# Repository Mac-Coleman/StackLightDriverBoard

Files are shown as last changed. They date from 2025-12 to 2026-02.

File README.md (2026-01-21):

# Stack Light Driver Board

This repository hosts my KiCad project.

Currently there is only a schematic.

Footprints and 3D models of most components are provided by [CDFER's JLCPCB component library for KiCad](https://github.com/CDFER/JLCPCB-Kicad-Library).

## Footprints and 3D models of the following components provided by SnapMagic:
* TSR_1-2433E
* 282837-2
* B2B-XH-A
* ESP32-S3-WROOM-1-N4
* PJ-102AH

## 3D models provided by Adafruit:
* MAX98357

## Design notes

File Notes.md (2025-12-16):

\[Datasheet](https://documentation.espressif.com/esp32-s3-wroom-1\_wroom-1u\_datasheet\_en.pdf)

Strapping pins are read after EN pin goes high.

GPIO0 and GPIO46 are needed to control which mode the ESP32 boots into.

GPIO0 has a weak pullup and GPIO46 has a weak pull-down. (13)

To boot normally and execute the program stored in SPI flash: GPIO0 is high and GPIO46 is any value. (14)

To boot into Joint Download Boot mode, GPIO0 must be 0 and GPIO46 must be 0. (14)

The program can then be flashed over USB interface.

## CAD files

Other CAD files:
3D Models/3006 MAX98357.step
3D Models/ltv5314.step
3D Models/5x20fuse.step
3D Models/littelfuse.step
3D Models/PJ-102AH.step
3D Models/ESP32-S3-WROOM-1-N4.step
3D Models/TSR 1-2433E.STEP
3D Models/B2B-XH-A.step
3D Models/282837-2.step

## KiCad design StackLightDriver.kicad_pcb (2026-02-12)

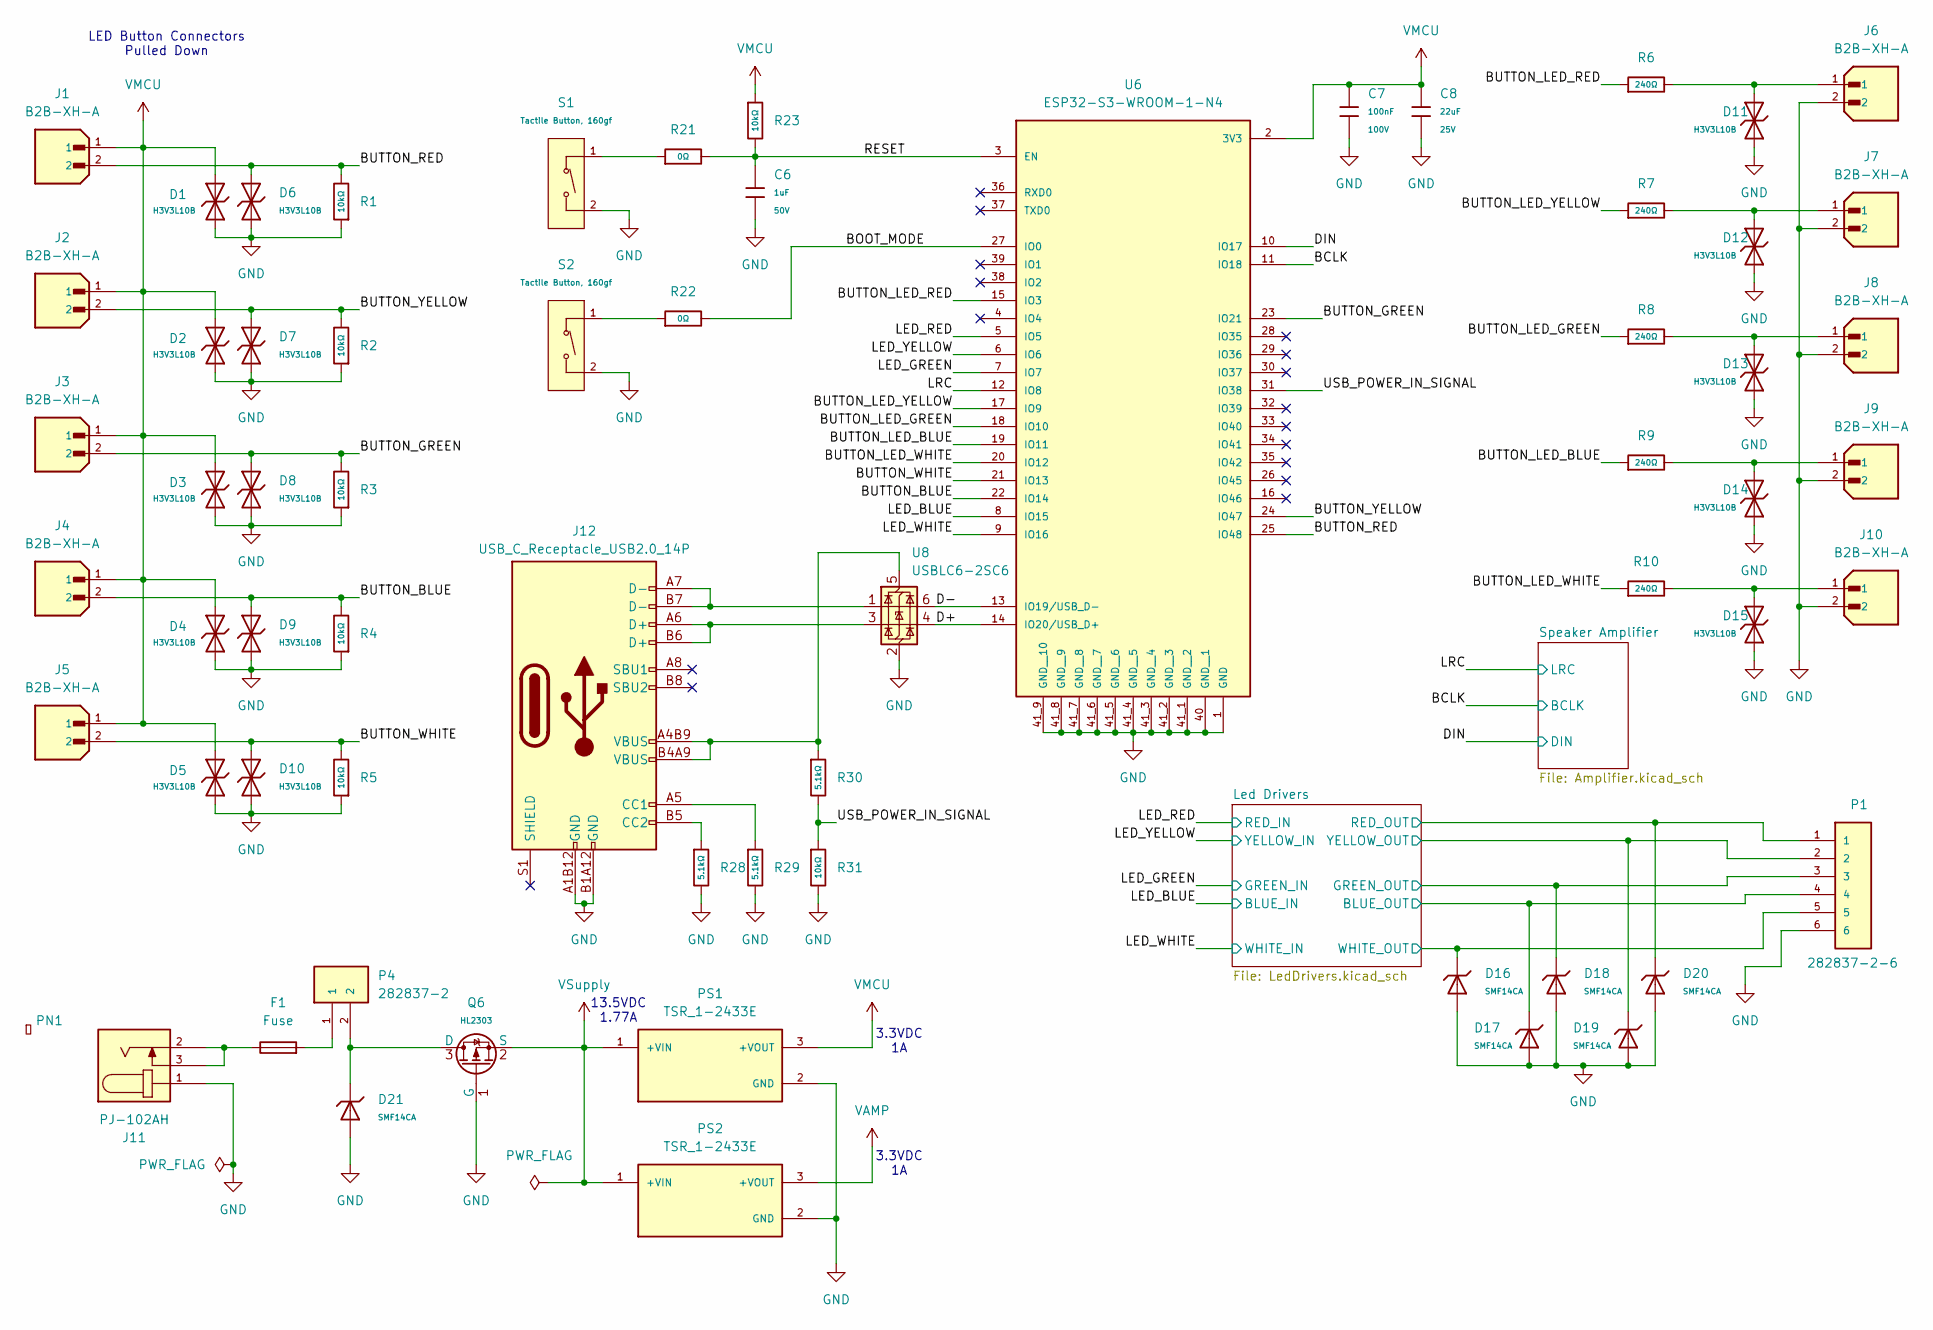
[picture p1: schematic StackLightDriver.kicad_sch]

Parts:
C6: 1uF; C_0805; Voltage Rated 50V; Tolerance ±10%; Part CL21B105KBFNNNE; LCSC C28323
C7: 100nF; C_0805; Voltage Rated 100V; Tolerance ±10%; Part CL21B104KCFNNNE; LCSC C28233
C8: 22uF; C_0805; Voltage Rated 25V; Tolerance ±20%; Part CL21A226MAQNNNE; LCSC C45783
D1, D2, D3, D4, D5, D6, D7, D8, D9, D10, D11, D12, D13, D14, D15: H3V3L10B; D_DFN1006-2L; Breakdown Voltage 5.5V; Part H3V3L10B; LCSC C20615781
D16, D17, D18, D19, D20, D21: SMF14CA; D_SOD-123FL; Part SMF14CA; LCSC C41411783
F1: Fuse; Fuseholder_Clip-5x20mm_Littelfuse_111_Lateral_P18.80x5.00mm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
J1, J2, J3, J4, J5, J6, J7, J8, J9, J10: B2B-XH-A; JST_B2B-XH-A; PARTREV N/A
J11: PJ-102AH; CUI_PJ-102AH
J12: USB_C_Receptacle_USB2.0_14P
P1: 282837-2-6; TE_282837-2-6; PARTREV G3
P4: 282837-2; TE_282837-2; PARTREV G3
PN1: Part_Num_JLCPCB
PS1, PS2: TSR_1-2433E; CONV_TSR_1-2433E; PARTREV May 25, 2020
Q6: HL2303; Q_SOT-23; Part HL2303; LCSC C7420345
R1, R2, R3, R4, R5, R23, R31: 10kΩ; R_0805; Overload Voltage (Max) 150V; Tolerance ±1%; Part 0805W8F1002T5E; LCSC C17414
R6, R7, R8, R9, R10: 240Ω; R_0805; Overload Voltage (Max) 150V; Tolerance ±1%; Part 0805W8F2400T5E; LCSC C17572
R21, R22: 0Ω; R_0805; Overload Voltage (Max) 150V; Tolerance ±1%; Part 0805W8F0000T5E; LCSC C17477
R28, R29, R30: 5.1kΩ; R_0805; Overload Voltage (Max) 150V; Tolerance ±1%; Part 0805W8F5101T5E; LCSC C27834
S1, S2: Tactile Button, 160gf; SW_TS-1088-AR02016; Voltage Rating (Dc) 12V; Part TS-1088-AR02016; LCSC C720477
U6: ESP32-S3-WROOM-1-N4; XCVR_ESP32-S3-WROOM-1-N4; PARTREV v1.0; Digikey 1965-ESP32-S3-WROOM-1-N4CT-ND
U8: USBLC6-2SC6; SOT-23-6; Digikey 497-5235-1-ND

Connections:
/BCLK: U6.11 (IO18); also elsewhere on the board
/BOOT_MODE: R22.2, U6.27 (IO0)
/BUTTON_BLUE: D9.2, J4.2, R4.2, U6.22 (IO14)
/BUTTON_GREEN: D8.2, J3.2, R3.2, U6.23 (IO21)
/BUTTON_LED_BLUE: R9.1, U6.19 (IO11)
/BUTTON_LED_GREEN: R8.1, U6.18 (IO10)
/BUTTON_LED_RED: R6.1, U6.15 (IO3)
/BUTTON_LED_WHITE: R10.1, U6.20 (IO12)
/BUTTON_LED_YELLOW: R7.1, U6.17 (IO9)
/BUTTON_RED: D6.2, J1.2, R1.2, U6.25 (IO48)
/BUTTON_WHITE: D10.2, J5.2, R5.2, U6.21 (IO13)
/BUTTON_YELLOW: D7.2, J2.2, R2.2, U6.24 (IO47)
/D+: U6.14 (IO20/USB_D+), U8.4 (I/O2)
/D-: U6.13 (IO19/USB_D-), U8.6 (I/O1)
/DIN: U6.10 (IO17); also elsewhere on the board
/LED_BLUE: U6.8 (IO15); also elsewhere on the board
/LED_GREEN: U6.7 (IO7); also elsewhere on the board
/LED_RED: U6.5 (IO5); also elsewhere on the board
/LED_WHITE: U6.9 (IO16); also elsewhere on the board
/LED_YELLOW: U6.6 (IO6); also elsewhere on the board
/LRC: U6.12 (IO8); also elsewhere on the board
/Led Drivers/BLUE_OUT: D17.1, P1.4; also elsewhere on the board
/Led Drivers/GREEN_OUT: D18.1, P1.3; also elsewhere on the board
/Led Drivers/RED_OUT: D20.1, P1.1; also elsewhere on the board
/Led Drivers/WHITE_OUT: D16.1, P1.5; also elsewhere on the board
/Led Drivers/YELLOW_OUT: D19.1, P1.2; also elsewhere on the board
/RESET: C6.1, R21.2, R23.2, U6.3 (EN)
/USB_POWER_IN_SIGNAL: R30.2, R31.1, U6.31 (IO38)
GND: C6.2, C7.2, C8.2, D1.1, D2.1, D3.1, D4.1, D5.1, D6.1, D7.1, D8.1, D9.1, D10.1, D11.1, D12.1, D13.1, D14.1, D15.1, D16.2, D17.2, D18.2, D19.2, D20.2, D21.2, J6.2, J7.2, J8.2, J9.2, J10.2, J11.1, J12.A1B12 (GND), J12.B1A12 (GND), P1.6, PS1.2 (GND), PS2.2 (GND), Q6.1 (G), R1.1, R2.1, R3.1, R4.1, R5.1, R28.2, R29.2, R31.2, S1.2 (B), S2.2 (B), U6.1 (GND), U6.40 (GND__1), U6.41_1 (GND__2), U6.41_2 (GND__3), U6.41_3 (GND__4), U6.41_4 (GND__5), U6.41_5 (GND__6), U6.41_6 (GND__7), U6.41_7 (GND__8), U6.41_8 (GND__9), U6.41_9 (GND__10), U6.41_10 (GND__11), U6.41_11 (GND__12), U6.41_12 (GND__13), U6.41_13 (GND__14), U6.41_14 (GND__15), U6.41_15 (GND__16), U6.41_16 (GND__17), U6.41_17 (GND__18), U6.41_18 (GND__19), U6.41_19 (GND__20), U6.41_20 (GND__21), U6.41_21 (GND__22), U8.2 (GND); also elsewhere on the board
unnamed: D11.2, J6.1, R6.2
unnamed: D12.2, J7.1, R7.2
unnamed: D13.2, J8.1, R8.2
unnamed: D14.2, J9.1, R9.2
unnamed: D15.2, J10.1, R10.2
unnamed: F1.1, J11.2, J11.3
unnamed: F1.2, P4.1
unnamed: J12.A5 (CC1), R29.1
unnamed: J12.B5 (CC2), R28.1
unnamed: J12.A6 (D+), J12.B6 (D+), U8.3 (I/O2)
unnamed: J12.A7 (D-), J12.B7 (D-), U8.1 (I/O1)
unnamed: D21.1, P4.2, Q6.3 (D)
unnamed: R21.1, S1.1 (A)
unnamed: R22.1, S2.1 (A)
unnamed: J12.A4B9 (VBUS), J12.B4A9 (VBUS), R30.1, U8.5 (VBUS)
VAMP: PS2.3 (+VOUT); also elsewhere on the board
VMCU: C7.1, C8.1, D1.2, D2.2, D3.2, D4.2, D5.2, J1.1, J2.1, J3.1, J4.1, J5.1, PS1.3 (+VOUT), R23.1, U6.2 (3V3)
VSupply: PS1.1 (+VIN), PS2.1 (+VIN), Q6.2 (S); also elsewhere on the board

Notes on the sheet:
3.3VDC 1A
13.5VDC 1.77A
LED Button Connectors Pulled Down

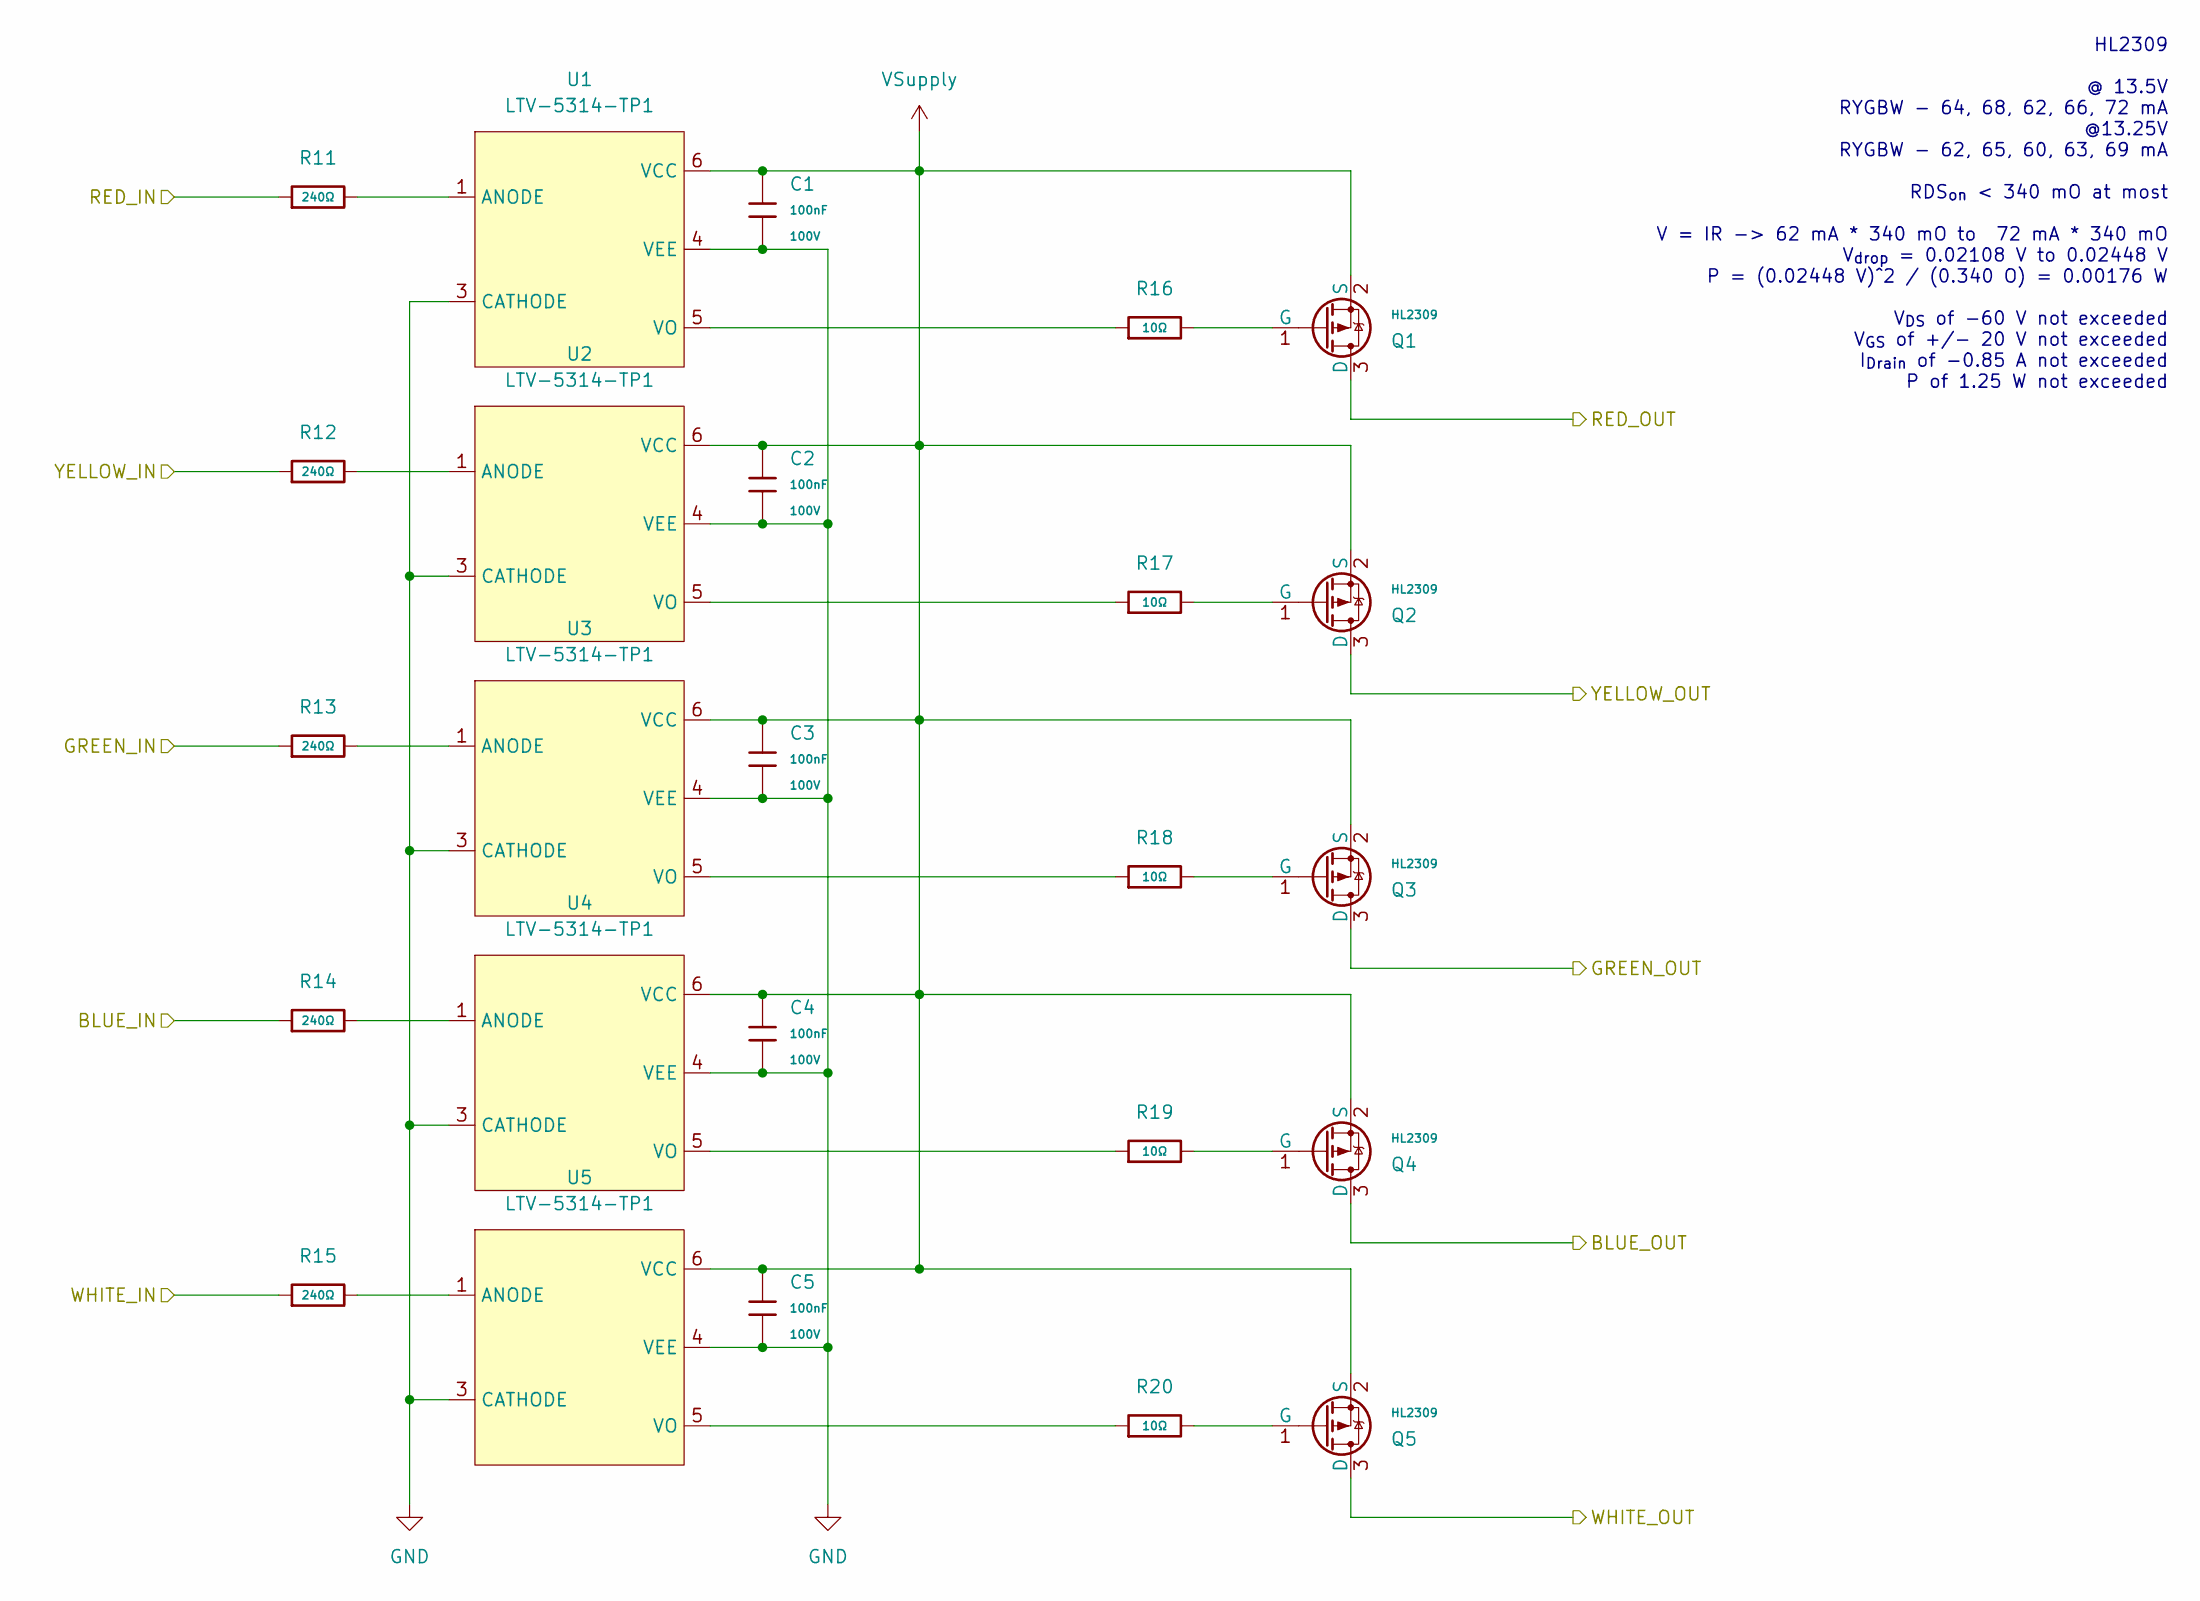
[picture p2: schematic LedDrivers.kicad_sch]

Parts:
C1, C2, C3, C4, C5: 100nF; C_0805; Voltage Rated 100V; Tolerance ±10%; Part CL21B104KCFNNNE; LCSC C28233
Q1, Q2, Q3, Q4, Q5: HL2309; Q_SOT-23; Part HL2309; LCSC C28646263
R11, R12, R13, R14, R15: 240Ω; R_0805; Overload Voltage (Max) 150V; Tolerance ±1%; Part 0805W8F2400T5E; LCSC C17572
R16, R17, R18, R19, R20: 10Ω; R_0805; Overload Voltage (Max) 150V; Tolerance ±1%; Part 0805W8F100JT5E; LCSC C17415
U1, U2, U3, U4, U5: LTV-5314-TP1; LCSC C2944034

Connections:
/LED_BLUE: R14.1; also elsewhere on the board
/LED_GREEN: R13.1; also elsewhere on the board
/LED_RED: R11.1; also elsewhere on the board
/LED_WHITE: R15.1; also elsewhere on the board
/LED_YELLOW: R12.1; also elsewhere on the board
/Led Drivers/BLUE_OUT: Q4.3 (D); also elsewhere on the board
/Led Drivers/GREEN_OUT: Q3.3 (D); also elsewhere on the board
/Led Drivers/RED_OUT: Q1.3 (D); also elsewhere on the board
/Led Drivers/WHITE_OUT: Q5.3 (D); also elsewhere on the board
/Led Drivers/YELLOW_OUT: Q2.3 (D); also elsewhere on the board
GND: C1.2, C2.2, C3.2, C4.2, C5.2, U1.3 (CATHODE), U1.4 (VEE), U2.3 (CATHODE), U2.4 (VEE), U3.3 (CATHODE), U3.4 (VEE), U4.3 (CATHODE), U4.4 (VEE), U5.3 (CATHODE), U5.4 (VEE); also elsewhere on the board
unnamed: Q1.1 (G), R16.2
unnamed: Q2.1 (G), R17.2
unnamed: Q3.1 (G), R18.2
unnamed: Q4.1 (G), R19.2
unnamed: Q5.1 (G), R20.2
unnamed: R11.2, U1.1 (ANODE)
unnamed: R16.1, U1.5 (VO)
unnamed: R12.2, U2.1 (ANODE)
unnamed: R17.1, U2.5 (VO)
unnamed: R13.2, U3.1 (ANODE)
unnamed: R18.1, U3.5 (VO)
unnamed: R14.2, U4.1 (ANODE)
unnamed: R19.1, U4.5 (VO)
unnamed: R15.2, U5.1 (ANODE)
unnamed: R20.1, U5.5 (VO)
VSupply: C1.1, C2.1, C3.1, C4.1, C5.1, Q1.2 (S), Q2.2 (S), Q3.2 (S), Q4.2 (S), Q5.2 (S), U1.6 (VCC), U2.6 (VCC), U3.6 (VCC), U4.6 (VCC), U5.6 (VCC); also elsewhere on the board

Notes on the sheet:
HL2309 @ 13.5V RYGBW - 64, 68, 62, 66, 72 mA @13.25V RYGBW - 62, 65, 60, 63, 69 mA RDS_{on} < 340 mO at most V = IR -> 62 mA * 340 mO to 72 mA * 340 mO V_{drop} = 0.02108 V to 0.02448 V P = (0.02448 V)^2 / (0.340 O) = 0.00176 W V_{DS} of -60 V not exceeded V_{GS} of +/- 20 V not exceeded I_{Drain} 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

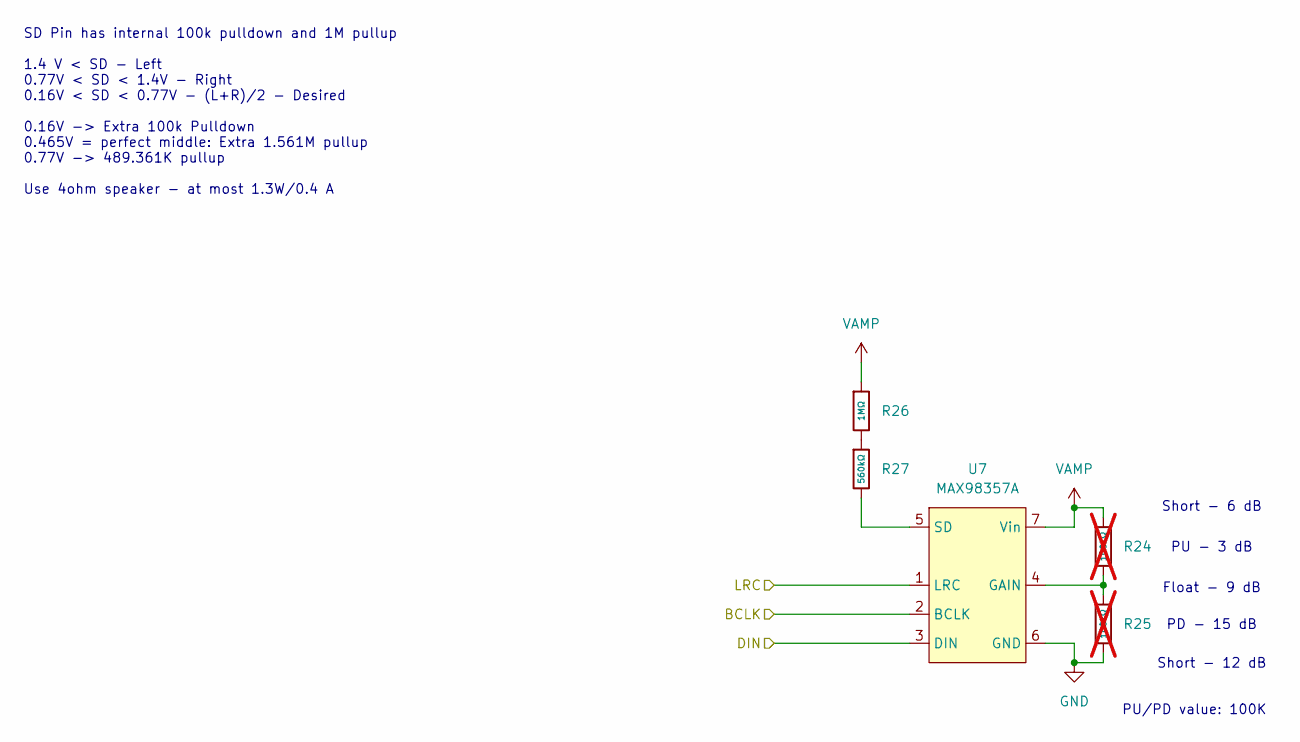
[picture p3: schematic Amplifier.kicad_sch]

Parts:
R24, R25: 100kΩ; R_0805; Overload Voltage (Max) 150V; Tolerance ±1%; Part 0805W8F1003T5E; LCSC C149504; not fitted
R26: 1MΩ; R_0805; Overload Voltage (Max) 150V; Tolerance ±1%; Part 0805W8F1004T5E; LCSC C17514
R27: 560kΩ; R_0603; Overload Voltage (Max) 75V; Tolerance ±1%; Part 0603WAF5603T5E; LCSC C23203
U7: MAX98357A; Adafruit_I2S_MAX98357A

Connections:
/BCLK: U7.2 (BCLK); also elsewhere on the board
/DIN: U7.3 (DIN); also elsewhere on the board
/LRC: U7.1 (LRC); also elsewhere on the board
GND: R25.2, U7.6 (GND); also elsewhere on the board
unnamed: R26.2, R27.1
unnamed: R24.2, R25.1, U7.4 (GAIN)
unnamed: R27.2, U7.5 (SD)
VAMP: R24.1, R26.1, U7.7 (Vin); also elsewhere on the board

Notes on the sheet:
PD - 15 dB
PU - 3 dB
Short - 6 dB
Float - 9 dB
SD Pin has internal 100k pulldown and 1M pullup 1.4 V < SD - Left 0.77V < SD < 1.4V - Right 0.16V < SD < 0.77V - (L+R)/2 - Desired 0.16V -> Extra 100k Pulldown 0.465V = perfect middle: Extra 1.561M pullup 0.77V -> 489.361K pullup Use 4ohm speaker - at most 1.3W/0.4 A
PU/PD value: 100K
Short - 12 dB

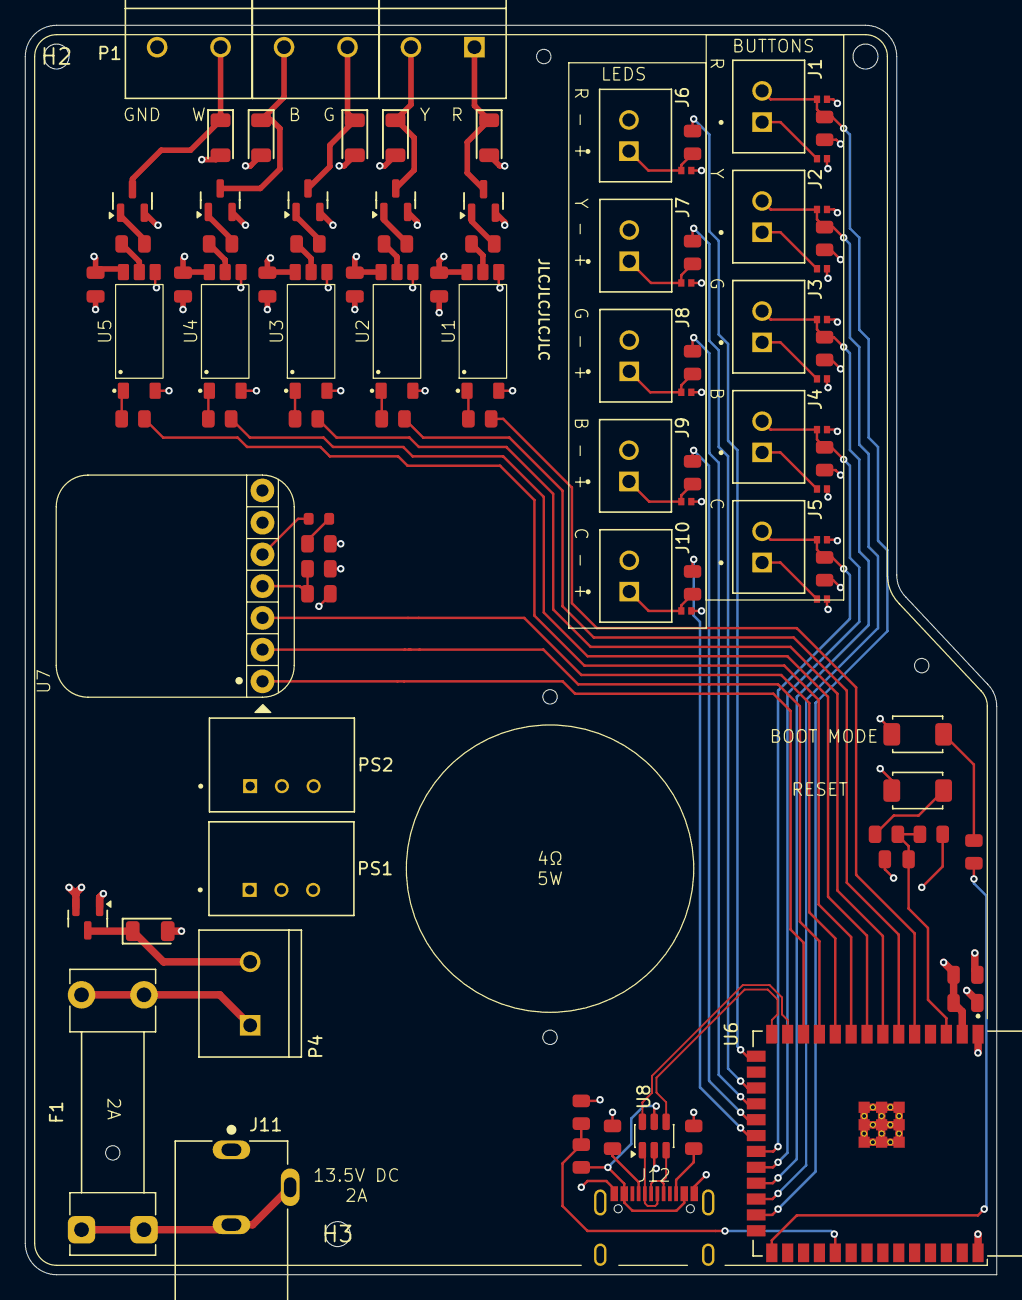
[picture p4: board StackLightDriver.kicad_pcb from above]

Board: 4 copper layers, 77.8 x 100.0 mm, 102 parts (0 on the bottom side), 65 nets.

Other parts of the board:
H1: Mounting_hole
H2: Mounting Hole
H3: Mounting hole
H4, H5, H6, H7, H8: Tooling_hole

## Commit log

2025-12-16 Recreated symbol/footprint libraries, added 3D models and Git LFS
    [282837-2.step, Amplifier.kicad_sch, B2B-XH-A.step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]
2025-12-16 Attribution of 3D models/symbols/footprints from SnapMagic
2025-12-16 Copied PCM_JLCPCB tactile switch symbol to change pins to passive for ERC
    [StackLightDriver.kicad_sch]
2025-12-16 Added 3D model and footprint for power jack
    [PJ-102AH.step, StackLightDriver.kicad_sch]
2025-12-16 Rearranged ESP32 symbol, added note file
    [StackLightDriver.kicad_sch]
2025-12-17 Added USB C connections and USB C TVS diodes
    [StackLightDriver.kicad_sch]
2026-01-19 Added basic Littelfuse clip model, began laying out PCB
    Still needs revisions to TVS diodes.
    [LedDrivers.kicad_sch, StackLightDriver.kicad_pcb, StackLightDriver.kicad_sch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]
2026-01-20 Added fuse models, LTV5314 models (Just step files for now)
    [5x20fuse.step, StackLightDriver.kicad_pcb, ltv5314.step]
2026-01-20 Rearranged components slightly, situating ESP32 better
    [StackLightDriver.kicad_pcb]
2026-01-21 Added models and footprint for Adafruit Max98357
    [3006 MAX98357.step, Amplifier.kicad_sch, StackLightDriver.kicad_pcb]
2026-01-22 Added some TVS diodes to schematic and to PCB layout
    [StackLightDriver.kicad_pcb, StackLightDriver.kicad_sch]
2026-01-26 Removed Test Points, reordered fuse and switch
    [StackLightDriver.kicad_sch]
2026-01-26 Updated USB C connector schematic symbol and added voltage divider
    [StackLightDriver.kicad_sch]
2026-02-04 Added reverse polarity mosfet
    [StackLightDriver.kicad_sch]
2026-02-04 Added footprint for USB-C receptacle
    [StackLightDriver.kicad_pcb, StackLightDriver.kicad_sch]
2026-02-04 Fixed incorrect decoupling capacitance on LTV5314
    [LedDrivers.kicad_sch, StackLightDriver.kicad_pcb]
2026-02-04 Placed TVS diodes on board
    [StackLightDriver.kicad_pcb]
2026-02-09 First routing attempt
    [StackLightDriver.kicad_pcb, StackLightDriver.kicad_sch]
2026-02-09 DRC adjustments
    [LedDrivers.kicad_sch, StackLightDriver.kicad_pcb]
2026-02-10 Mounting and tooling holes, silkscreen work
    [StackLightDriver.kicad_pcb, StackLightDriver.kicad_sch]
2026-02-11 Changed terminal block footprint, silkscreen changes, holes for speaker
    [StackLightDriver.kicad_pcb, StackLightDriver.kicad_sch]
2026-02-11 Silly silk screen stuff, re-verified ESP32 pins
    [StackLightDriver.kicad_pcb, StackLightDriver.kicad_sch]
2026-02-12 Terminal block courtyard, mounting/tooling hole references
    [StackLightDriver.kicad_pcb]
